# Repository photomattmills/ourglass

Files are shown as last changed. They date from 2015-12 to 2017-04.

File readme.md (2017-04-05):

#Ourglass

Board top from OSHPark

Board bottom from OSHPark

This is the code and design files for Ourglass, an open source watch. Feel free to use, modify, and extend in any way you see fit, all are released under the MIT license. http://ourglass.watch for updates.

#Contributing

Comments, questions, and pull requests welcome. This project follows a code of conduct (fully at code_of_conduct.md) and by contributing, you agree to abide by that code.

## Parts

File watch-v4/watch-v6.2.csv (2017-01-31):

Reference | Value | Footprint | Datasheet
U1 | IC_MCP73831 | Housings_SOT-23_SOT-143_TSOT-6:SOT-23-5
D2 | LED | Capacitors_SMD:C_0603
LIPOLY1 | BATTERY | Socket_Strips:molex_2_pos
R2 | 10kΩ | Resistors_SMD:R_0603
R1 | 47Ω | Resistors_SMD:R_0603
Q1 | MOSFET_P | Housings_SOT-23_SOT-143_TSOT-6:SOT-23
D1 | DIODESCH | Diodes_SMD:SOD-123
R3 | R100kΩ | Resistors_SMD:R_0603
U2 | MAX1722 | Housings_SOT-23_SOT-143_TSOT-6:SOT-23-5
L1 | 10uH | Resistors_SMD:R_1210
U3 | DS3231 | SMD_Packages:SOIC-8-N
R5 | 4.7k | Resistors_SMD:R_0603
R6 | 4.7k | Resistors_SMD:R_0603
U4 | LSM9DS0 | watch-v4:QFN-24-NO-CENTER4x4mm_Pitch0.5mm
C5 | .22uf | Capacitors_SMD:C_0603
C6 | 4.7uf | Capacitors_SMD:C_0603
C7 | 10uf | Capacitors_SMD:C_0603
C8 | 0.1uf | Capacitors_SMD:C_0603
J1 | CONN_10 | watch-v4:omron_XF2M-1015-1A-2
U5 | NRF51822 | Housings_DFN_QFN:UQFN-48-1EP_6x6mm_Pitch0.4mm
C10 | 12pf | Capacitors_SMD:C_0603
12pf1 | C9 | Capacitors_SMD:C_0603
X1 | 16mhz | watch-v4:SMD-Crystal
ANT1 | - | watch-v4:antenna
U6 | BALUN | watch-v4:BALUN-6
XL1 | USB_MICRO_B | watch-v4:USB_Micro-B
C13 | 0.1uf | Capacitors_SMD:C_0603
C14 | 1nf | Capacitors_SMD:C_0603
C2 | 4.7uf | Capacitors_SMD:C_0603
C1 | 1uf | Capacitors_SMD:C_0603
C3 | 4.7uf | Capacitors_SMD:C_0603
P1 | Expansion Header | crennelated:SIP-12
C11 | 2n2 | Capacitors_SMD:C_0603
C9 | 47n | Capacitors_SMD:C_0603
C4 | 100n | Capacitors_SMD:C_0603
R7 | 10M | Resistors_SMD:R_0603
R8 | 10M | Resistors_SMD:R_0603
C12 | 1u | Capacitors_SMD:C_0603
R4 | 10k | Resistors_SMD:R_0603

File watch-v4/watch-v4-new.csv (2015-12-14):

Reference | Value | Footprint | Datasheet
U1 | IC_MCP73831 | Housings_SOT-23_SOT-143_TSOT-6:SOT-23-5
D2 | LED | LEDs:LED-0603
LIPOLY1 | BATTERY | watch-v4:Pin_Header_Straight_1x02
R2 | 10kΩ | Resistors_SMD:R_0603
R1 | 47Ω | Resistors_SMD:R_0603
Q1 | MOSFET_P | Housings_SOT-23_SOT-143_TSOT-6:SOT-23
D1 | DIODESCH | Diodes_SMD:SOD-123
R3 | R100kΩ | Resistors_SMD:R_0603
U2 | MAX1722 | Housings_SOT-23_SOT-143_TSOT-6:SOT-23-5
L1 | 10uH | Resistors_SMD:R_1210
U3 | DS3231 | SMD_Packages:SOIC-8-N
R5 | 4.7k | Resistors_SMD:R_0603
R6 | 4.7k | Resistors_SMD:R_0603
U4 | LSM9DS0 | watch-v4:QFN-24-NO-CENTER4x4mm_Pitch0.5mm
C5 | .22uf | Capacitors_SMD:C_0603
C6 | 4.7uf | Capacitors_SMD:C_0603
C7 | 10uf | Capacitors_SMD:C_0603
C8 | 0.1uf | Capacitors_SMD:C_0603
J1 | CONN_10 | watch-v4:omron_XF2M-1015-1A-2
U5 | NRF51822 | Housings_DFN_QFN:UQFN-48-1EP_6x6mm_Pitch0.4mm
C10 | 12pf | Capacitors_SMD:C_0603
12pf1 | C9 | Capacitors_SMD:C_0603
X1 | 16mhz | watch-v4:SMD-Crystal
ANT1 | - | watch-v4:antenna
U6 | BALUN | watch-v4:BALUN
C12 | 2.2nf | Capacitors_SMD:C_0603
SW1 | SPST | watch-v4:panasonic-evpav-switch
SW2 | SPST | watch-v4:panasonic-evpav-switch
SW3 | SPST | watch-v4:panasonic-evpav-switch
XL1 | USB_MICRO_B | watch-v4:USB_Micro-B
C13 | 0.1uf | Capacitors_SMD:C_0603
C14 | 0.1uf | Capacitors_SMD:C_0603
P1 | array connection | watch-v4:Pin_Header_Straight_1x02
C2 | 4.7uf | Capacitors_SMD:C_0603
C1 | 1uf | Capacitors_SMD:C_0603
C3 | 4.7uf | Capacitors_SMD:C_0603

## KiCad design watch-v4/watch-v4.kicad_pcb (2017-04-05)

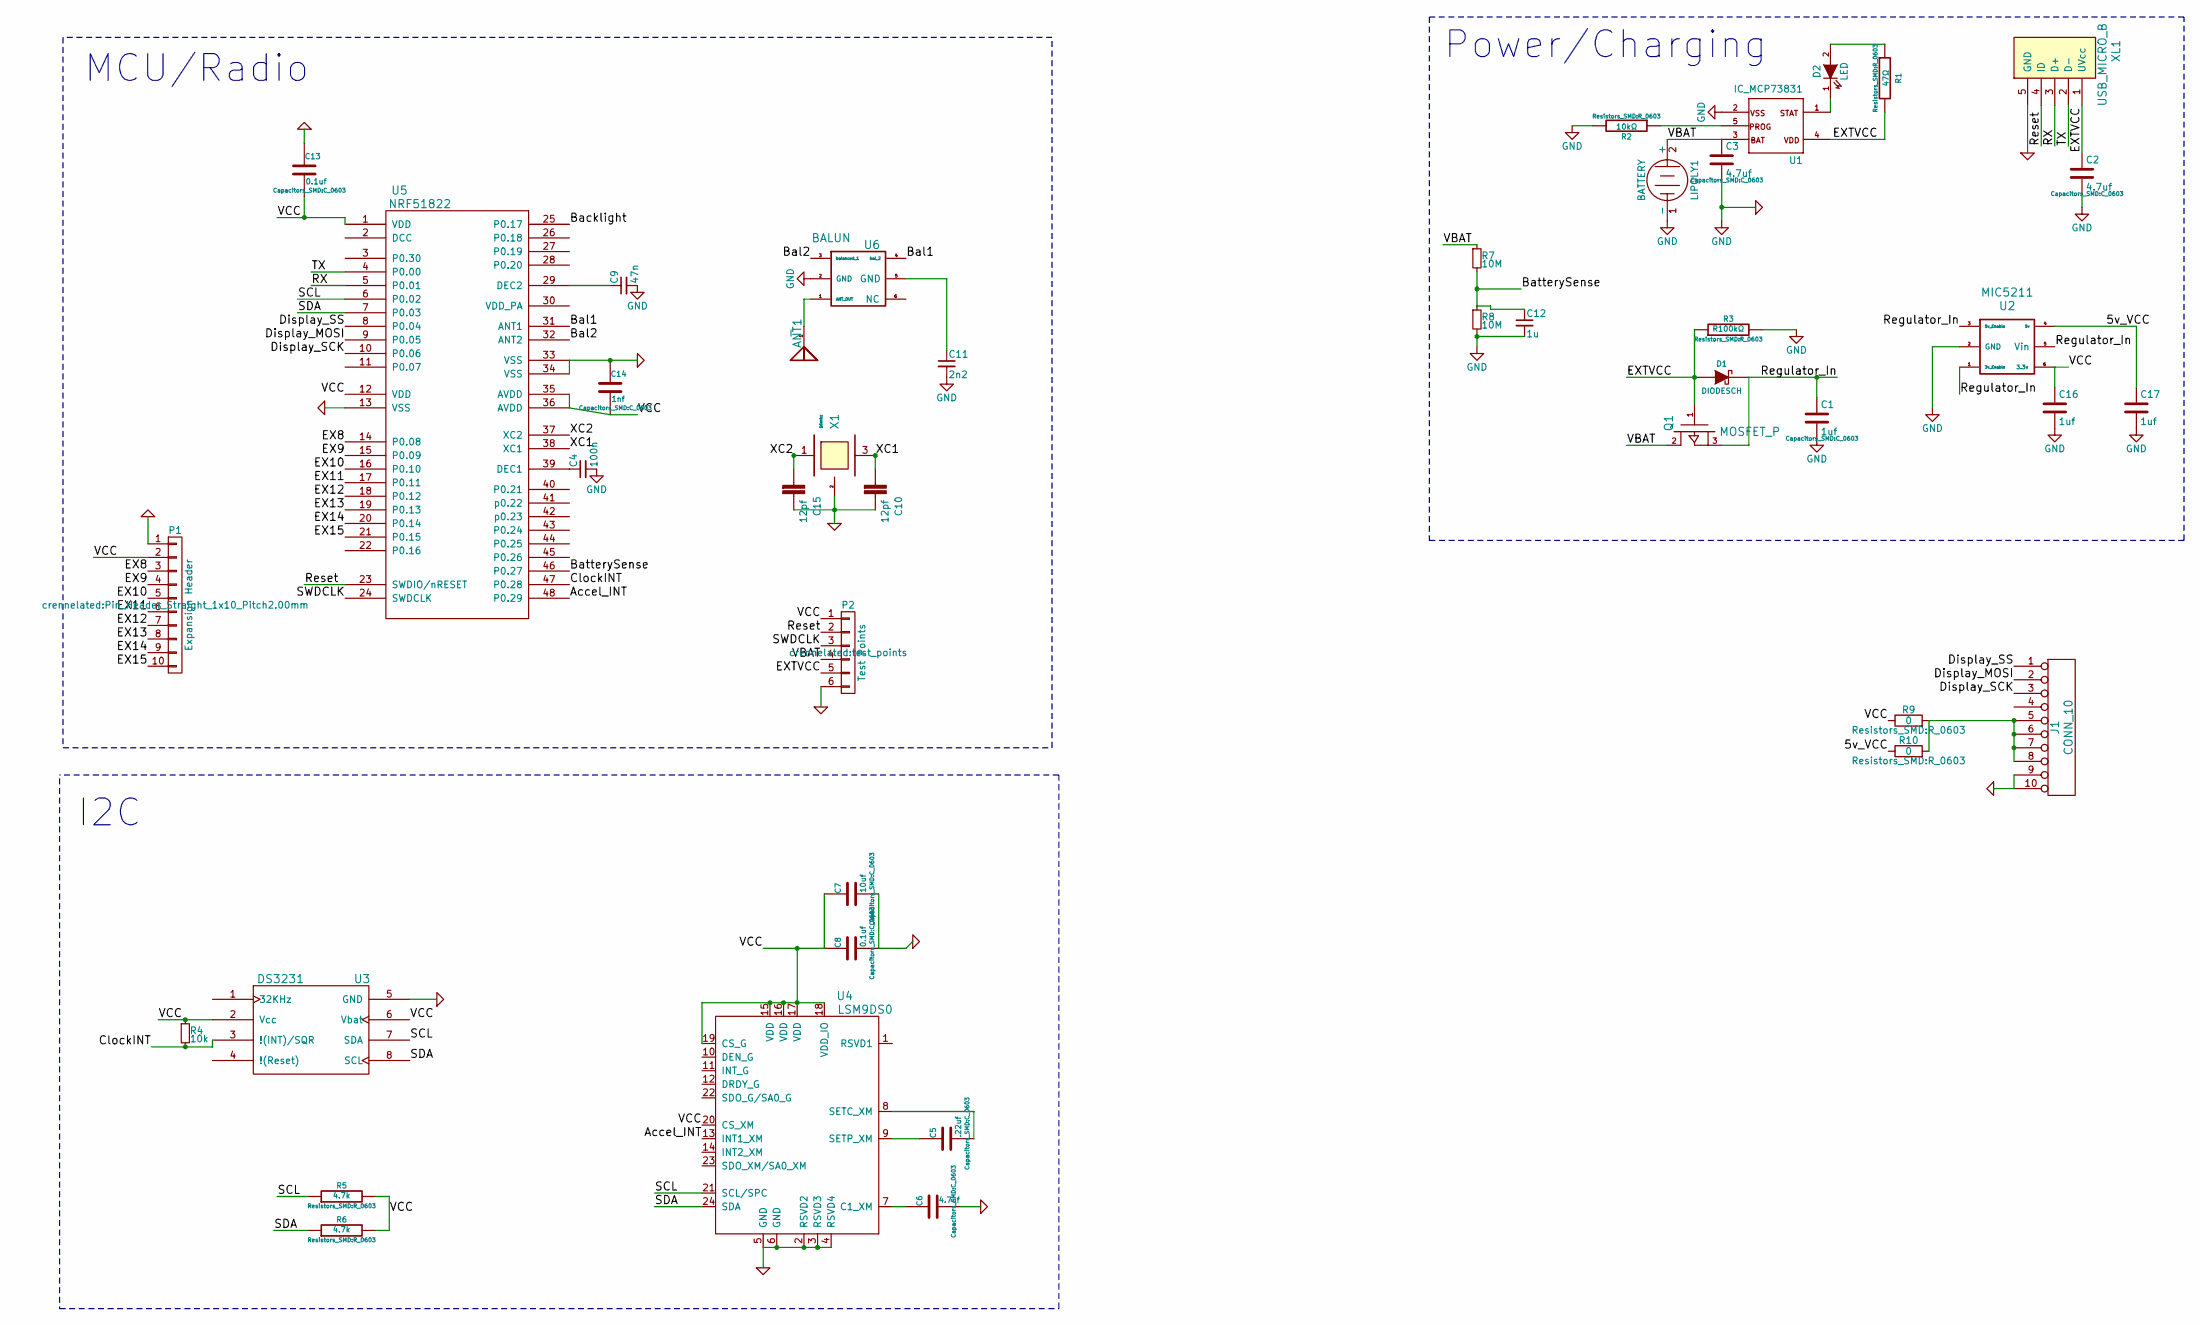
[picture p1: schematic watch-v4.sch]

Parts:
ANT1: -; antenna
C1, C16, C17: 1uf; C_0603
C2, C3, C6: 4.7uf; C_0603
C4: 100n; C_0603
C5: .22uf; C_0603
C7: 10uf; C_0603
C8, C13: 0.1uf; C_0603
C9: 47n; C_0603
C10, C15: 12pf; C_0603
C11: 2n2; C_0603
C12: 1u; C_0603
C14: 1nf; C_0603
D1: DIODESCH; SOD-123
D2: LED; C_0603
J1: CONN_10; omron_XF2M-1015-1A-2
LIPOLY1: BATTERY; JST_2_pos
P1: Expansion Header; Pin_Header_Straight_1x10_Pitch2.00mm
P2: Test Points; test_points
Q1: MOSFET_P; SOT-23
R1: 47Ω; R_0603
R2: 10kΩ; R_0603
R3: R100kΩ; R_0603
R4: 10k; R_0603
R5, R6: 4.7k; R_0603
R7, R8: 10M; R_0603
R9, R10: 0; R_0603
U1: IC_MCP73831; SOT-23-5
U2: MIC5211; SOT-23-6
U3: DS3231; SOIC-8-N
U4: LSM9DS0; QFN-24-NO-CENTER4x4mm_Pitch0.5mm
U5: NRF51822; UQFN-48-1EP_6x6mm_Pitch0.4mm
U6: BALUN; BALUN-6
X1: 16mhz; SMD-Crystal
XL1: USB_MICRO_B; USB_Micro-B

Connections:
/5v_VCC: C17.1, R10.1, U2.4 (5v)
/Accel_INT: U4.13 (INT1_XM), U5.48 (P0.29)
/Bal1: U5.31 (ANT1), U6.4 (bal_2)
/Bal2: U5.32 (ANT2), U6.3 (balanced_1)
/BatterySense: C12.1, R7.2, R8.1, U5.46 (P0.27)
/ClockINT: R4.2, U3.3 (!(INT)/SQR), U5.47 (P0.28)
/Display_MOSI: J1.2, U5.9 (P0.05)
/Display_SCK: J1.3, U5.10 (P0.06)
/Display_SS: J1.1, U5.8 (P0.04)
/EX8: P1.3, U5.14 (P0.08)
/EX9: P1.4, U5.15 (P0.09)
/EX10: P1.5, U5.16 (P0.10)
/EX11: P1.6, U5.17 (P0.11)
/EX12: P1.7, U5.18 (P0.12)
/EX13: P1.8, U5.19 (P0.13)
/EX14: P1.9, U5.20 (P0.14)
/EX15: P1.10, U5.21 (P0.15)
/EXTVCC: C2.1, D1.1 (A), P2.5, Q1.1 (G), R1.2, R3.1, U1.4 (VDD), XL1.1 (UVcc)
/RX: U5.5 (P0.01), XL1.3 (D+)
/Regulator_In: C1.1, D1.2 (K), Q1.3 (S), U2.1 (3v_Enable), U2.3 (5v_Enable), U2.5 (Vin)
/Reset: P2.2, U5.23 (SWDIO/nRESET), XL1.4 (ID)
/SCL: R5.1, U3.7 (SDA), U4.21 (SCL/SPC), U5.6 (P0.02)
/SDA: R6.1, U3.8 (SCL), U4.24 (SDA), U5.7 (P0.03)
/SWDCLK: P2.3, U5.24 (SWDCLK)
/TX: U5.4 (P0.00), XL1.2 (D-)
/VBAT: C3.1, LIPOLY1.2 (+), P2.4, Q1.2 (D), R7.1, U1.3 (BAT)
/VCC: C7.1, C8.1, C13.2, C14.2, C16.1, P1.2, P2.1, R4.1, R5.2, R6.2, R9.1, U2.6 (3.3v), U3.2 (Vcc), U3.6 (Vbat), U4.15 (VDD), U4.16 (VDD), U4.17 (VDD), U4.18 (VDD_IO), U4.19 (CS_G), U4.20 (CS_XM), U5.1 (VDD), U5.12 (VDD), U5.35 (AVDD), U5.36 (AVDD)
/XC1: C10.1, U5.38 (XC1), X1.3
/XC2: C15.1, U5.37 (XC2), X1.1
GND: C1.2, C2.2, C3.2, C4.2, C6.2, C7.2, C8.2, C9.2, C10.2, C11.2, C12.2, C13.1, C14.1, C15.2, C16.2, C17.2, J1.9, J1.10, LIPOLY1.1 (-), P1.1, P2.6, R2.2, R3.2, R8.2, U1.2 (VSS), U2.2 (GND), U3.5 (GND), U4.2 (RSVD2), U4.3 (RSVD3), U4.4 (RSVD4), U4.5 (GND), U4.6 (GND), U5.13 (VSS), U5.33 (VSS), U5.34 (VSS), U6.2 (GND), X1.2, XL1.5 (GND)
unnamed: ANT1.1, U6.1 (ANT_OUT)
unnamed: C4.1, U5.39 (DEC1)
unnamed: C5.1, U4.9 (SETP_XM)
unnamed: C5.2, U4.8 (SETC_XM)
unnamed: C6.1, U4.7 (C1_XM)
unnamed: C9.1, U5.29 (DEC2)
unnamed: C11.1, U6.5 (GND)
unnamed: D2.1 (K), U1.1 (STAT)
unnamed: D2.2 (A), R1.1
unnamed: J1.5, J1.6, J1.7, J1.8, R9.2, R10.2
unnamed: R2.1, U1.5 (PROG)

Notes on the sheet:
Power/Charging
I2C
MCU/Radio

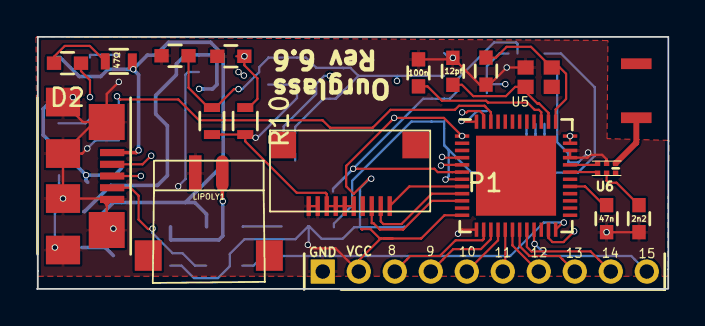
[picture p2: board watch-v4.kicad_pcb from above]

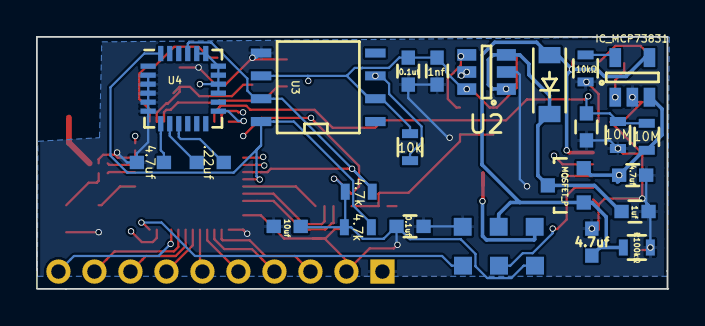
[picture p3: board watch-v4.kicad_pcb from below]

Board: 4 copper layers, 35.1 x 14.0 mm, 43 parts (24 on the bottom side), 41 nets.

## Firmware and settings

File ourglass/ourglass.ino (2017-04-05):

#include <Wire.h>
#include "RTClib.h"
#include <SPI.h>
#ifndef  __sharp__
#include <Adafruit_GFX.h>
#include <Adafruit_SharpMem.h>
#endif
#include "analog_face.h"
#include "digital_face.h"
#include <Adafruit_Sensor.h>
#include <Adafruit_LSM9DS0.h>
#include <math.h>

#include <RFduinoBLE.h>

RTC_DS1307 rtc;

Adafruit_SharpMem display(SCK, MOSI, SS);

AnalogFace analog_face(&display, &rtc);
DigitalFace digital_face;
long ms;
long display_time;

int menu_active;

#define BLACK 1
#define WHITE 0

Adafruit_LSM9DS0 lsm = Adafruit_LSM9DS0(1000);
uint32_t steps = 0;
bool    step_debounce;

const int button1 = 8;
const int button2 = 9;
const int button3 = 10;
const int clock_int = 28;
const int battery_sense = 1;

void setup () {
  Wire.beginOnPins(3,2);
  SPI.begin();
  display.begin();
  display.clearDisplay();
  display.setTextColor(BLACK);
  if (rtc.now().unixtime() < 1486924071){
    rtc.adjust(DateTime(__DATE__, __TIME__));
  }

// need to remember wth this is doing at some point
  Wire.beginTransmission(0x68);
  Wire.write(0x0E);
  Wire.write(0b00000000);
  Wire.endTransmission();

  // lsm.begin();
  // lsm.setupAccel(lsm.LSM9DS0_ACCELRANGE_2G);
  // lsm.setupMag(lsm.LSM9DS0_MAGGAIN_2GAUSS);
  // lsm.enableFIFO();

  // setup for buttons

//  setup for clock interrupt
  pinMode(clock_int, INPUT); // set pin 28 to input
  pinMode(battery_sense, INPUT); // set pin 27 to input
  RFduino_pinWakeCallback(clock_int, LOW, screen_redraw);
  RFduino_pinWakeCallback(button2, HIGH, menu_mode);
  RFduino_pinWakeCallback(button3, HIGH, item_down);
  RFduino_pinWakeCallback(button1, HIGH, item_up);

  // setup the radio
  // RFduinoBLE.advertisementData = "data";
  // RFduinoBLE.deviceName = "ourglass";
  // RFduinoBLE.txPowerLevel = -4;
  // RFduinoBLE.begin();
}

long square(long x){
  return (x * x);
}

void checkStep (DateTime now){
  if (now.unixtime() % (3600*24) == 0) {
    steps = 0;
  }
  uint8_t samples = lsm.fifoSamples();

  long current_gs;

  for (uint8_t i=0; i<samples && i<32 ; i++){
    lsm.read();
    long x_2 = square(lsm.accelData.x);
    long y_2 = square(lsm.accelData.y);
    long z_2 = square(lsm.accelData.z);
    current_gs = sqrt(x_2+y_2+z_2);
    bool step = (current_gs > 30000 || current_gs < 5000);
    if (!step_debounce && step){
      steps++;
      step_debounce = true;
    }else if(!step){
      step_debounce = false;
    }
  }

  display.setTextSize(1);
  display.setCursor(10, 61);
  display.print(steps);
}

void loop() {
  RFduino_ULPDelay(INFINITE);
}

String zero_pad(int number){
  if (number < 10) {
    return "0" + String(number);
    }
  else {
    return String(number);
  }
}

int menu_mode(uint32_t pin){
  menu_active++;
  screen_redraw(pin);
  return 0;
}

int screen_redraw(uint32_t pin){
  draw_watchface(pin);
  // if(menu_active % 2 == 0) {
  // }
  // else{
  //   draw_menu(pin);
  // }
  return 0;
}

int draw_watchface(uint32_t ulPin){
  DateTime now = rtc.now();
  // analog_face.displayAnalog();
  display.clearBuffer();
  display.setCursor(2,5);
  digital_face.displayDigital(now, display, 5, 40);
  // display.setCursor(59, 105);

  // display.println(zero_pad(rtc.now().second()));
  // display.println(menu_active);

  // display.setCursor(40,95);
  // Convert the analog reading (which goes from 0 - 1023) to a voltage (0 - 3.3V):
  int sensorValue = analogRead(battery_sense);
  // float voltage = sensorValue * (3.3/1023.0);
  // display.print(voltage*2);
  display.print(sensorValue - 520);
  display.print("/85");

  display.setCursor(2,87);
  display.print(zero_pad(now.month()));
  display.print('/');
  display.print(zero_pad(now.day()));
  display.print('/');
  display.print(zero_pad(now.year()));
  display.print(' ');
  display.print(' ');
  display.print(analog_face.day(now.unixtime()));
  display.refresh();


  return 0;
}

// menu specific variables that I'll need to put somewhere else eventually
char* menuItems[]={"Set Time", "Set TZ", "Exit"};
long display_delay_time;
int active_item;
int max_items = 3;

int draw_menu(uint32_t pin){
  display.clearDisplay();
  display.setCursor(1,1);
  display.setTextSize(2);

  for (size_t current_item = 0; current_item < max_items; current_item++) {
    if (current_item == active_item % max_items) {
      display.setTextColor(WHITE, BLACK);
      display.println(menuItems[current_item]);
    } else {
      display.setTextColor(BLACK, WHITE);
      display.println(menuItems[current_item]);
    }
  }
  // display.println(active_item);
  digital_face.displayDigital(rtc.now(), display, 0, 100);
  display.refresh();
  return 0;
}

int item_down(uint32_t pin){
  active_item++;
  screen_redraw(pin);
  return 0;
}
int item_up(uint32_t pin){
  active_item--;
  screen_redraw(pin);
  return 0;
}

int action(uint32_t pin){
  return 0;
}

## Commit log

2015-06-15 add all the files for the board design
    [watch-v4.csv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]
2015-06-20 move files for arduino IDE and add code of conduct
2015-06-22 board errata, new gerber files
    [$watch-v4.sch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]
2015-06-23 change display footprint, move filter cap to feasible location
    [watch-v4.kicad_pcb]
2015-06-27 escape from git hell
    [$watch-v4.sch, watch-v4.sch]
2015-07-21 schematic cleanup, board work
    [watch-v4.kicad_pcb, watch-v4.sch]
2015-07-22 re-route board, redraw power supply in schematic
    [watch-v4.0.kicad_pcb, watch-v4.kicad_pcb, watch-v4.sch]
2015-07-23 forgot to netlist the new parts; now with more caps, connections
    [watch-v4.kicad_pcb, watch-v4.sch]
2015-12-14 add 4.5 gerbers
    [watch-v4-new.csv, watch-v4.0.kicad_pcb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]
2015-12-14 re-add watch hw files
    [watch-v4-new.csv, watch-v4.csv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]
2016-04-12 up to version 5.2
    [_saved_watch-v4.sch, watch-v4.kicad_pcb]
2016-05-22 save v5.2
    [_saved_watch-v4.sch, watch-v4.kicad_pcb, watch-v4.sch]
2016-10-14 save schematic changes for 5.4
    [watch-v4.sch]
2016-10-14 v6 schematic updates
    * add expansion header
    * remove buttons
    * fix radio decoupling, gnd connections
    * change backlight to mosfet/standard leds
    * add battery connection through voltage divider
    * clock INT pullup on schematic now
    [watch-v4.sch]
2016-10-14 get rid of the global labels, tidy things up a bit
    [watch-v4.sch]
2016-10-14 more cleanup
    [watch-v4.sch]
2016-10-17 further v6 work; incomplete
    [watch-v4.kicad_pcb, watch-v4.sch]
2016-10-18 further traces routed, still more work to go
    [_saved_watch-v4.sch, watch-v4.kicad_pcb]
2016-10-20 top layer components mostly routed
    [_saved_watch-v4.sch, watch-v4.kicad_pcb, watch-v4.sch]
2016-10-24 routed all the things
    [_saved_watch-v4.sch]
2016-11-30 v6 as sent to fab (errors!)
    [_saved_watch-v4.sch, watch-v4.kicad_pcb, watch-v4.sch]
2017-01-31 update avr_watch with the current sketch with battery meter
2017-03-17 update board image in readme
2017-03-17 add image of board back
2017-04-05 switch out the regulator
    [_saved_watch-v4.sch, watch-v4.kicad_pcb, watch-v4.sch]
